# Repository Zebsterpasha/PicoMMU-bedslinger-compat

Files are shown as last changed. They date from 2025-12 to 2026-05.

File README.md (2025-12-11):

# PicoMMU-bedslinger-compat
A collection of compatibility adaptations and user-level improvements for PicoMMU and related Klipper MMU tools, focused on bedslinger printers such as the Ender-3.
This repository does not replace or compete with the original PicoMMU project — it provides optional adjustments that improve reliability and usability on specific motion systems.

Included components:

PicoMMU bedslinger compatibility layer
Adjustments and fixes tailored for bedslinger (Y-axis moving bed) printers.

Filametrix Ender-series adaptation
A customized variant optimized for Ender-class machines.

Printer automation scripts
Helper utilities, including automatic shutdown and filament-handling scripts.

These resources are intended as community contributions for users who operate PicoMMU or similar MMU setups on bedslinger printers.

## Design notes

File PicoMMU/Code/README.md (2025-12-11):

# What's been done:
- Fixed bugs:
    - heating was turned off if a filament change was required at the start of a print
    - PRINT_END was fixed to ensure the print completes correctly
- Added temperature recovery before RESUME
- Changed the print return sequence for bed_slinger (first return to the desired Z height, and only then XY)
- Added Z parking point
- Added pregate (and actually postgear) sensor configuration
- Added a service for automatically loading filament to the HUB via the pregate sensor

To use the automatic filament loading service:
- Add a file pregate_autoload.py to /home/*USER*/klipper/klippy/extras/
- Add an import "from . import pregate_autoload" to the file /home/*USER*/klipper/klippy/extras/__init__.py

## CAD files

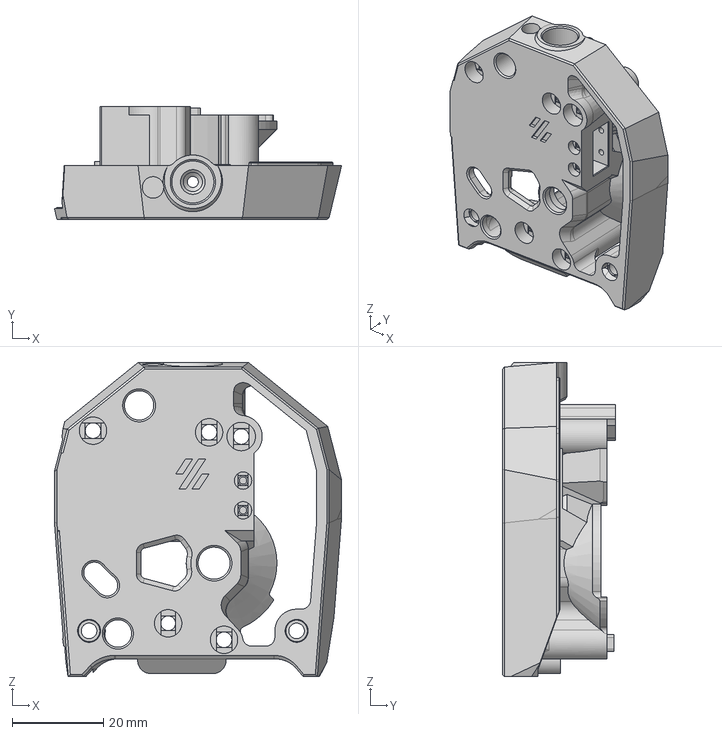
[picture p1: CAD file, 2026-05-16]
Filametrix_Ender3Pro/CAD/FilamatrixEndtopMotorPlate.step
62.8 x 24.7 x 68.7 mm

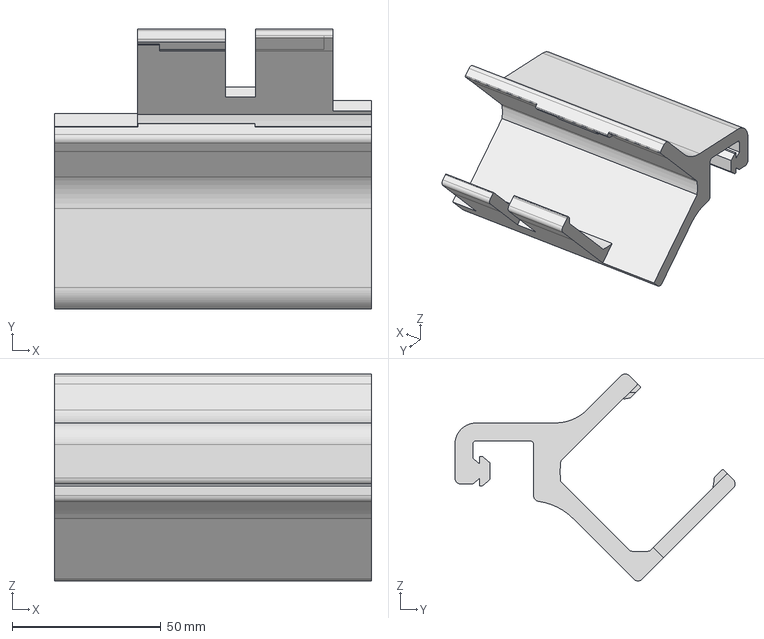
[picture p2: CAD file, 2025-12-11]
PicoMMU/Models/CAD/PicoMMU_20x20_Mount.step
106.4 x 94.1 x 69.5 mm

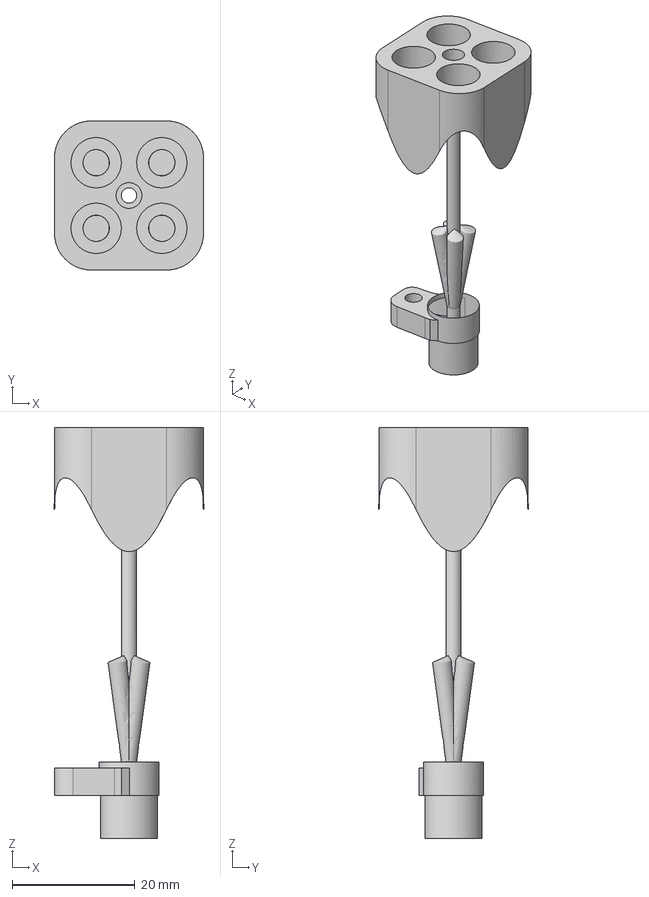
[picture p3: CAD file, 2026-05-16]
Filametrix_Ender3Pro/CAD/LongSmoothHub.step
24.3 x 24.3 x 67.0 mm

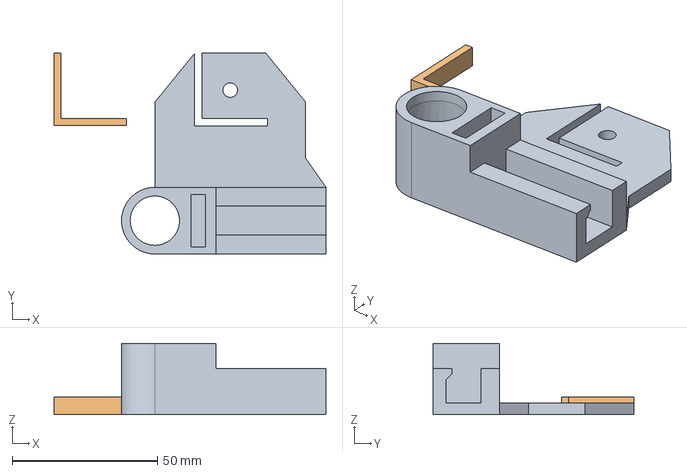
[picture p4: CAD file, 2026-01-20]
Filametrix_Ender3Pro/CAD/Purge bucket v6.step
93.8 x 69.3 x 24.5 mm

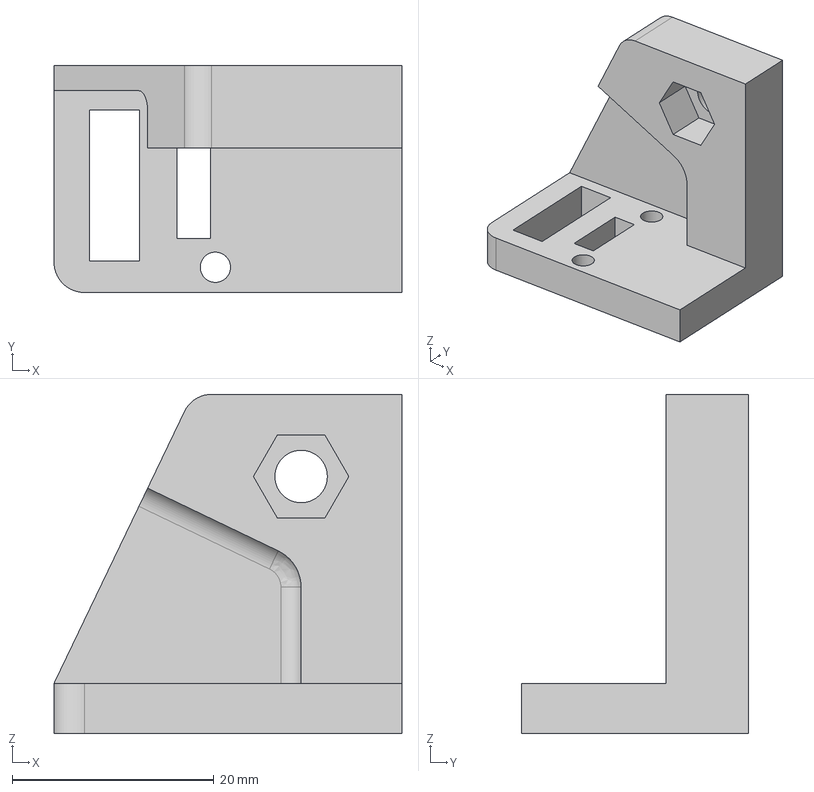
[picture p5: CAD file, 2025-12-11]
Filametrix_Ender3Pro/CAD/Positive X endstop bracket v3.step
34.5 x 22.5 x 33.7 mm

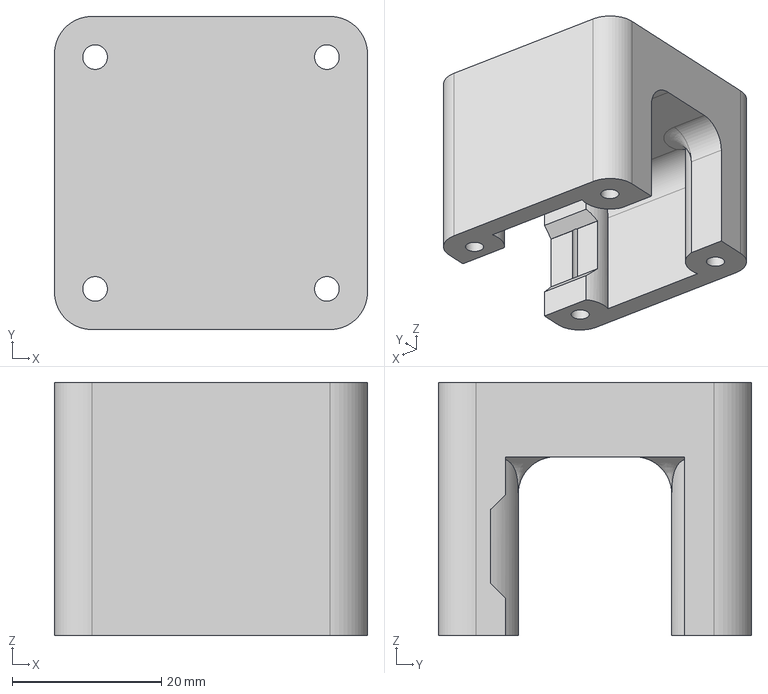
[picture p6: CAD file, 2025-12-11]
Filametrix_Ender3Pro/CAD/X-Cover Ender3 no endstop v1.step
42.0 x 42.0 x 34.0 mm

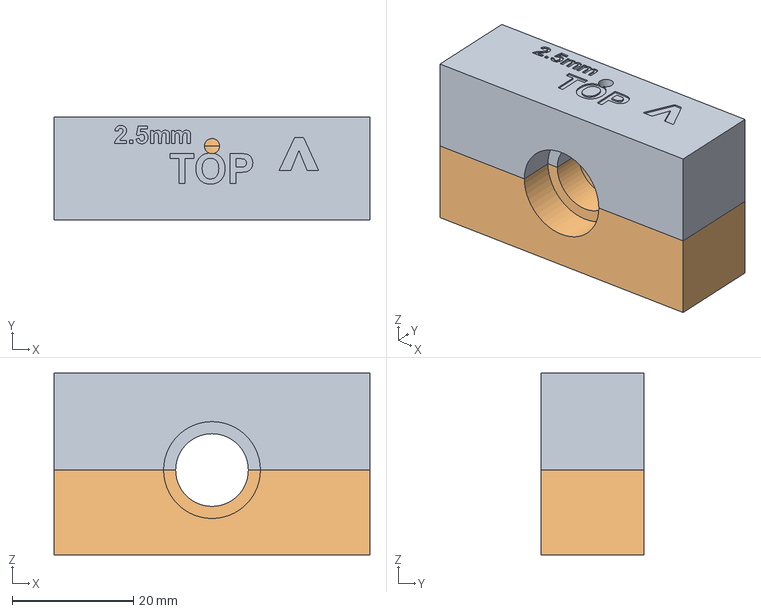
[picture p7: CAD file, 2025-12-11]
Filametrix_Ender3Pro/CAD/Drilling_Guide_Jig.step
52.2 x 17.0 x 30.0 mm

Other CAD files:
Filametrix_Ender3Pro/STL/Drilling_Guide_Jig.stl
Filametrix_Ender3Pro/STL/FilamatrixEndtopMotorPlate.stl
Filametrix_Ender3Pro/STL/LongSmoothHub.stl
Filametrix_Ender3Pro/STL/Positive X endstop bracket v3.stl
Filametrix_Ender3Pro/STL/Purge bucket v6.stl
Filametrix_Ender3Pro/STL/X-Cover Ender3 no endstop v1.stl
PicoMMU/Models/STL/PicoMMU_20x20_Mount.stl

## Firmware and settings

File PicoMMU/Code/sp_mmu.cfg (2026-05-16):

### CONFIGURATION TEMPLATE VERSION: 0.9.2

###_______________  LH STINGER PICO MMU  _____________________
### https://github.com/lhndo/LH-Stinger/wiki/Pico-MMU
### This code is licensed under a Creative Commons (4.0 International License)Attribution—Noncommercial—Share Alike




### ------  SETUP  ------
### Add [include sp_mmu.cfg] to printer.cfg BELOW all other includes or macros!
### Klipper Setup: https://github.com/lhndo/LH-Stinger/wiki/Pico-MMU#klipper
### Orca Slicer Setup: https://github.com/lhndo/LH-Stinger/wiki/Pico-MMU#slicer-setup


### ------  MACROS  ------
### Use the dropdown arrow on the macro buttons to set extra parameters
### Macro Documentation: https://github.com/lhndo/LH-Stinger/wiki/Pico-MMU#macros




### ------  HARDWARE CONFIGURATION  -----------------------------------------------------------
###
### This example configuration is based on a BTT EBB42 V1.2 board
### Firmware flashed for USB connection: https://github.com/bigtreetech/EBB/tree/master
### Pinout: https://github.com/lhndo/LH-Stinger/wiki/Images/MMU/ebb_wiring.png
### Provided by Nick1 and DasSammy


[mcu PICO_MMU]
serial: /dev/serial/by-id/usb-Klipper_stm32g0b1xx_550035000F504D4D37393820-if00

[duplicate_pin_override]
pins: PICO_MMU: PB3   # Filament Sensor pin


[servo sp_servo]
pin: PICO_MMU: PB9    # Servo pin
initial_angle: 0
maximum_servo_angle: 140
minimum_pulse_width: 0.000700
maximum_pulse_width: 0.002300


[manual_stepper sp_motor]  
step_pin: PICO_MMU: PD0                 # Motor Pins
dir_pin: !PICO_MMU: PD1                 # Motor Pins
enable_pin: !PICO_MMU: PD2              # Motor Pins
full_steps_per_rotation: 200
rotation_distance: 18.64                # Needs calibration after final tuning - start with a 10mm forward movement to eliminate backlash, and then extrude 100mm for measurement - use SP_FORCE_MOVE_LANE for calibrating distances
endstop_pin: ^PICO_MMU: PB3             # Filament Sensor pin - keep ^ pullup symbol
microsteps: 16


[tmc2209 manual_stepper sp_motor]
uart_pin: PICO_MMU: PA15   # Motor Pins
run_current: 0.7           # Adjust depending on your motor current ( Motor Rated Current * 0.707(RMS) * 0.8(Safety Factor) )
hold_current: 0.4
interpolate: true
stealthchop_threshold: 99999
 

[filament_switch_sensor sp_sensor_runout]
switch_pin: ^PICO_MMU: PB3
pause_on_runout: False
insert_gcode:
  _SP_SENSOR_IN
runout_gcode:
  _SP_SENSOR_OUT
event_delay: 0.5
pause_delay: 1.0

[filament_switch_sensor mmu_pregate_0]
switch_pin: ^PICO_MMU: PB6
pause_on_runout: False

[filament_switch_sensor mmu_pregate_1]
switch_pin: ^PICO_MMU: PB5
pause_on_runout: False

[filament_switch_sensor mmu_pregate_2]
switch_pin: ^PICO_MMU: PB7
pause_on_runout: False

[filament_switch_sensor mmu_pregate_3]
switch_pin: ^PICO_MMU: PB8
pause_on_runout: False

[pregate_autoload] 
# это для автоматической догрузки филамента от pregate sensor до hub см klipper/klippy/extras/pregate_autoload.py и __init__.py

[save_variables]
filename: ~/printer_data/sp_mmu_data.cfg   ### Don't change this path if not having an explicit need to do so
[force_move]
enable_force_move: true
[respond]




### ------  VARIABLES  ------------------------------------------------------------------------
### Default distances calibrated on the LH Stinger in the extended Dragon HF configuration (MZE Plus extender) witn an Orbiter 2 extruder and a Toolhead Hub


[gcode_macro _SP_VARS]

variable_enabled: 1    # enable or disable the LH Stinger Pico MMU


# Lanes
variable_lanes: 4                 # number of lanes on the Pico MMU
variable_has_guest_lane: 1        # enable guest lane support (eg. 3+1 setups) - the guest lane uses the last filament set in the slicer
variable_angles: 34, 66, 100, 129  # angles where the lanes are engaged | approximate defaults: 28, 78, 128 for 3 lanes | 28, 61, 94, 128 for 4 lanes
variable_angle_home: 0            # home positions where no lane is engaged, usually at 0
variable_switch_time: 1.2         # seconds - safe time value it takes for the servo to reach the max commanded angle from zero 


# Distances                              # Illustration: https://github.com/lhndo/LH-Stinger/wiki/Images/MMU/toolhead.png - Documentation: https://github.com/lhndo/LH-Stinger/wiki/Pico-MMU#distance-calibration
variable_dist_mmu_to_hub: 425            # mm - distance from the mmu exit to the hub park position (set it just above the hub entry so you can see the filament tip above)  
variable_dist_hub_to_sensor: 100         # mm - distance from the hub park position to the filament sensor trigger point
variable_dist_sensor_to_extruder: 12     # mm - distance from the filament sensor to the point where the filament touches the extruder gears 
variable_dist_extruder_to_meltzone: 71   # mm - distance from the extruder gears to the meltzone entry (a tiny bit further from where the filament breaks off from) - compensate with end_of_load_filament_move
variable_dist_sensor_to_synced_move: 8   # mm - distance from the filament sensor towards the extruder from where the extruder and mmu unit start working in sync to load the filament - around half way between the sensor and the extruder for toolhead hub configs 
variable_dist_filament_park: 26.5        # mm - distance from the extruder gears to the filament parking position inside the hotend - nice cold section closer to the extruder - For Filament Cutter: set this to the cut position 


# Speeds
variable_speed_mmu_to_hub: 80        # mm/s - speed for loading the filament from the MMU towards the hub 
variable_speed_hub_to_extruder: 50   # mm/s - filament loading speed from the hub towards the extruder gears
variable_speed_sync_moves: 14        # mm/s - loading speed for synced moves (extruder and mmu motors working in tandem) 
variable_speed_coldzone_loading: 35  # mm/s - moving the filament though the coldzone
variable_speed_meltzone_loading: 10  # mm/s - moving the filament though the meltzone - this is dependent to your hotend max volumetric flow. lower if extruder skips


# Inside Extruder Loading
variable_min_loading_temp: 240           # C - temperature to use if the hotend is cold and no temperature target was set
variable_end_of_load_filament_move: -4   # mm - what to do when the filament has reached the meltzone after loading - negative values: subtract | positive: purge - tweak until no ooze happens after loading filament into the hotend - note that manual changes purge by default
variable_print_start_change_purge: 80    # mm - of filament of purge if a change is made before starting a print 
variable_purge_speed: 7                  # mm3/s - volumetric speed of the purge move


# Motor
variable_motor_speed: 40     # mm/s - default mmu stepper motor speed
variable_motor_accel: 500    # mm2/s - default mmu stepper motor acceleration


# Pause
variable_pause_fan_speed: 0.3       # -1 disable part fan control at pause,  0 to 1.0 - fan speed at pause - can prevent heat creep especially during initial layers
variable_pause_retract: 1.0         # mm - amount of filament to retract and reload at the begining/end of the pause/resume cycle
variable_sidestep_amount: 4         # mm - 0 disabled - move to the side of the purge tower before a toolchange - only when park is disabled


# Park
variable_use_park: 1                # 0 disabled - park during filament changes or stay next to the purge tower
variable_park_purge: 1              # 0/1 - on/off - purge the required amount of filament for a color change calculated by the slicer and sent though _SP_SET_PURGE PURGE=[first_flush_volume] 
variable_purge_unload: 0            # mm - distance - distance of filament to purge before unloading the hotend - helps with tip forming - only when park_purge is enabled 
variable_park_x: 20                 # mm absolute - park x
variable_park_y: 5                  # mm absolute - park y
variable_park_dz: 2                 # mm delta park z hop
variable_park_z: 0.5                # mm absolute - park z
variable_park_z_speed: 20           # mm/s speed for park moves
variable_park_speed: 100            # mm/s speed for park moves
variable_park_accel: 2000           # mm2/s acceleration for park moves
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

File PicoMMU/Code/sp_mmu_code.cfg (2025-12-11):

### Do not edit or include this file into printer.cfg
### REQUIRES CONFIGURATION TEMPLATE VERSION: 0.9.2

###_______________  LH STINGER PICO MMU  _____________________
### https://github.com/lhndo/LH-Stinger/wiki/Pico-MMU
### This code is licensed under a Creative Commons (4.0 International License)Attribution—Noncommercial—Share Alike




#### ------ BOOT INIT ----------


[delayed_gcode _SP_BOOT]
initial_duration: 3
gcode:
  {% set sp = printer['gcode_macro _SP_VARS'] %}
  {% set loaded_lane = printer.save_variables.variables.last_loaded_lane | default(-2) | int %}
  {% set legacy = sp.legacy_klipper|int if sp.legacy_klipper is defined else 99 %} 
 
  {% if sp.enabled == 1 %}
    RESPOND MSG="---- LH Stinger Pico MMU Enabled ----"
    RESPOND MSG=""

    {% if legacy == 1 %}
      RESPOND MSG="SP:Legacy Klipper mode Enabled"
      {% if printer.configfile.settings.extruder.min_extrude_temp|int >= 20 %}
        RESPOND TYPE=error MSG="SP: Extruder min_extrude_temp and min_temp from printer.cfg [extruder] has to be set to 0 !!!"
      {% endif %}
    {% endif %}

    {% if loaded_lane >= 0 %}
      RESPOND MSG="SP: Loaded Extruder Lane saved: {printer.save_variables.variables.last_loaded_lane}"
    {% else %}
      RESPOND MSG="SP: No loaded LANE saved in memory"
    {% endif %}
    
    RESPOND MSG="SP: Initializing LH Stinger Pico MMU"
    {% if sp.has_guest_lane == 1 %} 
      SET_GCODE_VARIABLE MACRO=_SP_VARS VARIABLE=lanes VALUE={sp.lanes + 1}  ## extending the number of lanes to include the guest lane
    {% endif %}
    _SP_NOTIFY ACTION="boot" 
    _SP_REFRESH_STATE
    SP_INIT
    _CHECK_SETTINGS_VERSION_SP
  
  {% else %}
    SET_FILAMENT_SENSOR SENSOR=sp_sensor_runout ENABLE=0
  {% endif %}



[gcode_macro SP_INIT]
gcode:
  {% set sp = printer['gcode_macro _SP_VARS'] %}
  {% set rt = printer['gcode_macro _SP_VARS_RUNTIME'] %}
  {% set loaded_lane = printer.save_variables.variables.last_loaded_lane | default(-2) | int %}
  RESPOND MSG="SP: Initializing Pico MMU"
  SET_FILAMENT_SENSOR SENSOR=sp_sensor_runout ENABLE=0
  SET_GCODE_VARIABLE MACRO=_SP_VARS_RUNTIME VARIABLE=next_purge VALUE={sp.print_start_change_purge} ## Setting the purge amount to the user set value
  
  {% if rt.is_filament_in == 1 %}
    RESPOND MSG="SP: Inserted filament detected"

    {% if loaded_lane < 0 %}
      RESPOND MSG="SP: WARNING! Unknown LANE loaded! Please verify your system and use SP_FORCE_SET_LOADED_LANE LANE=<0...> to manually set the loaded lane"
      RESPOND MSG="SP: WARNING! Defaulting to LANE 0! Please correct if not accurate!"
      _SP_UI_MSG MSG="Unknown LANE loaded!  Defaulting to LANE 0.  Please correct if not accurate" TITLE="WARNING"
      _SP_SET_LOADED_LANE LANE=0
      SAVE_VARIABLE VARIABLE=hotend_loaded VALUE=1
      _SP_NOTIFY ACTION="loaded" LANE=0 COMPLETE=1 ERROR=1 
    {% else %}
      RESPOND MSG="SP: >>>> Loaded LANE {printer.save_variables.variables.last_loaded_lane} <<<< "  
      _SP_NOTIFY ACTION="loaded" LANE={printer.save_variables.variables.last_loaded_lane} COMPLETE=1
    {% endif %}

  {% else %}
      {% if printer.save_variables.variables.last_loaded_lane != -1  %}
        RESPOND MSG="SP: WARNING! Last set LANE was {printer.save_variables.variables.last_loaded_lane}, but no filament is detected! Resetting lane memory"
      {% endif %}

      _SP_SET_LOADED_LANE LANE=-1
      SAVE_VARIABLE VARIABLE=hotend_loaded VALUE=0
      SET_GCODE_VARIABLE MACRO=_SP_VARS_RUNTIME VARIABLE=is_filament_in VALUE=0
      RESPOND MSG="SP: Filament not present in the hotend"             
  {% endif %}

  SP_HOME
  SP_CLEAR_ERROR_CODES 
  _SP_RESET_VARIABLES
  _SP_REFRESH_STATE



### The macro below is broken into A B parts to obtain refreshed variables for error checking
[gcode_macro _SP_PRINT_START]
gcode:
  {% set lane = params.LANE| default(-1) | int %}
  {% set temp = params.TEMP| default(0) | int %}
  {% set no_start_purge = params.NO_START_PURGE | default(0) | int %}
  {% set unload_lane = printer.save_variables.variables.last_loaded_lane | default(-1) | int %}
  {% set sp = printer['gcode_macro _SP_VARS'] %}
  {% set rt = printer['gcode_macro _SP_VARS_RUNTIME'] %}
  {% set purge_amount = sp.print_start_change_purge if no_start_purge == 0 else 0 %}

  CLEAR_PAUSE
   
  {% if sp.enabled == 1  %}
    RESPOND MSG="SP: Print Start - Resetting the SP MMU"    
    _SP_REFRESH_STATE
    SP_INIT
  
    {% if lane+1 <= sp.lanes and lane >= 0 %}
   
      {% if lane != unload_lane %}        
        RESPOND MSG="SP: ----- Filament Change: LANE {unload_lane} >>>> LANE {lane} ----- "
        SET_GCODE_VARIABLE MACRO=_SP_VARS_RUNTIME VARIABLE=print_start_change VALUE=1

        # Park
        M400
        {% if sp.use_park == 1 and sp.skip_first_park == 0 %}
          _SP_CONDITIONAL_HOME
          _SP_PAUSE_PARK
        {% endif %} 

        ## User Macro Before Change
        M400
        {% if rt.user_macros_executed == 0 %} # if user macro can be executed
          RESPOND MSG="SP: Running User BEFORE_CHANGE Macro"
          SAVE_GCODE_STATE NAME=user_macro
          _SP_BEFORE_CHANGE PRINT_START=1
          M400
          SET_GCODE_VARIABLE MACRO=_SP_VARS_RUNTIME VARIABLE=user_macros_executed VALUE=1
          RESTORE_GCODE_STATE NAME=user_macro
        {% endif %}
 
        ### Filament Change Routine 
        _SP_FILAMENT_CHANGE UNLOAD_LANE={unload_lane} LOAD_LANE={lane} TEMP={temp} PURGE={purge_amount}        
        M400
        _SP_RESTORE_PA FORCE=1
        _SP_REFRESH_STATE
        M400
        _SP_PRINT_START_B


      {% else %}
        RESPOND MSG="SP: No filament change required"             
        RESPOND MSG="SP: Starting print with LANE {lane}"
        SET_FILAMENT_SENSOR SENSOR=sp_sensor_runout ENABLE=1
        SET_GCODE_VARIABLE MACRO=_SP_VARS_RUNTIME VARIABLE=next_purge VALUE=0 ## Setting next purge amount to 0 since no change was required
        SP_CLEAR_ERROR_CODES
      {% endif %}
       
     {% else %}
       RESPOND TYPE=error MSG="SP: ERROR: Invalid LANE inputs. LANE {unload_lane} and loading LANE {lane}"
       _SP_NOTIFY ACTION="empty" COMPLETE=1 ERROR=1 
       _SP_SET_EXIT_CODE CODE=1
     {% endif %}

    _SP_REFRESH_STATE   

  {% else %}
    RESPOND MSG="The SP MMU is not enabled for this print"
  {% endif %}



[gcode_macro _SP_PRINT_START_B]
gcode:
  {% set sp = printer['gcode_macro _SP_VARS'] %}
  {% set rt = printer['gcode_macro _SP_VARS_RUNTIME'] %}
  
  {% if sp.enabled == 1 %}
  
    {% if rt.exit_code == 0 %}

      ## User Macro After Change
      M400
      {% if rt.user_macros_executed == 1 %}
        RESPOND MSG="SP: Running User AFTER_CHANGE Macro"
        SAVE_GCODE_STATE NAME=user_macro
        _SP_AFTER_CHANGE PRINT_START=1
        M400
        RESTORE_GCODE_STATE NAME=user_macro
      {% endif %}  

      RESPOND MSG="SP: Continuing. Please wait"
      RESPOND MSG="SP: Enabling filament runout sensor"
      SET_FILAMENT_SENSOR SENSOR=sp_sensor_runout ENABLE=1
      _SP_REFRESH_STATE
      #RESPOND MSG="SP: Turning off hotend before the actual print start"
      #M104 S0 # Turn off hotend before the actual print start
      
    {% else %}
      RESPOND TYPE=error MSG="SP: Turning off hotend and PAUSING"
      M104 S0 # Turn off hotend for safety
      SP_HOME
      _SP_NOTIFY ACTION="pause" ERROR=1 
      
      PAUSE
    {% endif %}
    _SP_REFRESH_STATE
    SET_GCODE_VARIABLE MACRO=_SP_VARS_RUNTIME VARIABLE=user_macros_executed VALUE=0  ## Clearing execution even if print start change fails
  {% endif %} 



[gcode_macro _SP_PRINT_END]
gcode:
  RESPOND MSG="SP: ---- Print Ended ----"
  RESPOND MSG="SP: Resetting LH Stinger Pico MMU "
  RESPOND MSG=""
  _SP_NOTIFY ACTION="print_end" 
  _SP_SHOW_STATISTICS
  SET_FILAMENT_SENSOR SENSOR=sp_sensor_runout ENABLE=0
  SP_UNLOAD_LANE



### Implementation for RatOS T0 conflict
### The T macros are commented in pico_mmu.cfg
### In Orca Slicer add Change filament G-code: SP_CHANGE T=[next_extruder]
[gcode_macro _SP_CHANGE]
gcode:
  _SP_REFRESH_STATE   
  _SP_TOOL_CHANGE LANE={params.T|int}
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

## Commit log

2025-12-11 Initial changes commit
    [Drilling_Guide_Jig.step, Drilling_Guide_Jig.stl, PicoMMU_20x20_Mount.step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]
2026-01-20 Fixed park position for custom purge bucket. Added purge bucket models
    [Purge bucket v6.step, Purge bucket v6.stl, sp_mmu.cfg]
2026-05-16 EndstopMotorPlate and filamentHub have been added + some updates
    [FilamatrixEndtopMotorPlate.step, FilamatrixEndtopMotorPlate.stl, LongSmoothHub.step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]
